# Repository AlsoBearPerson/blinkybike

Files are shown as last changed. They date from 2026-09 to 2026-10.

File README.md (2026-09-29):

# Blinkybike

This is the source for a small hobby bike-modding project,
adding some microcontroller-driven RGB lighting to a bicycle.

If you're curious about how it's built,
here's some of the under-the-hood bits.

As a general principle,
the software is supposed to focus on readability and maintability,
over golfing performance.
However, it is also a prototype, and I'm still learning the language,
so there will be quirks.

## Not a recipe

The project is provided solely for reference, as an example of
some practical application of rust-embedded shenanigans.
In particular, it is NOT intended as a ready-made recipe for
easy adaptation: it may contain assumptions of particular
hardware quirks, undocumented subtlety,
and backwards-incompatible changes may happen at any time as I feel like it.
I'm just one internet-connected potato making things,
I have no bandwidth available for any kind of support efforts.

## Parts

For reference, here's the parts being used to drive this, as-built.
These were what I picked up randomly and should not be read as endorsements,
better parts may exist and I did not do systematic market analysis,
but in the spirit of reproducability, here's the major parts used:

### A bicycle

If you don't know what this is, I can't help you.
Mine's acoustic (not electric, powered entirely by my own two legs).

### Microcontroller

Using a [Pi Pico 2W](https://www.raspberrypi.com/products/raspberry-pi-pico-2/?variant=pico-2-w).

It's more than enough power for what we need,
and BLE support means we can make a control UI driven by a common smartphone,
rather than having to wire up and attach our own switches/buttons/knobs.

### Debug Probe

Not strictly necessary, but very useful for troubleshooting,
I'd highly recommend grabbing a [Pi Debug Probe](https://www.raspberrypi.com/products/debug-probe/),
which can connect to the SWD interface on the pico.
This allows both debugging, and also just reflashing the pico anytime
without having to reboot or fiddle with BOOTSEL buttons.

Then you'll want to grab [probe.rs](https://probe.rs/)
which can upload and run builds, and interface with the `defmt` and `RTT` shenanigans,
so you get cheap accurate logging and even panic stacktraces,
even though you're running on a microcontroller.

### Blinky Bits

I'm using a [LED fake-neon-tube strip](https://www.adafruit.com/product/3869).

Any WS2812-style "neopixel" strip would work,
the nice thing about the fake neon is that it's a pretty omnidirectional glow,
and the diffusion avoids any sharp point lights,
which might be uncomfortable to look at.

BEWARE: This thing takes some specific handling:
it only bends in one axis, which is great for making neon-like signs,
but a problem for us, if we want to fix it to a 3D object.
Internally, it's a flex-PCB LED strip turned sideways,
thus it bends well side-to-side, twists somewhat,
but REALLY dislikes bending up/down,
if you force it you'll likely rip the PCB.
Be generous with bend radiuses, and try to twist before/after bends,
to keep them along the preferred axis.

Note that this one takes 12V power, which is nice to keep amps low,
but means yet more voltages to worry about.

### Level Shifting

This might not be strictly necessary,
but I'm using an [Adafruit Pixel Shifter](https://www.adafruit.com/product/6066).

Note that the strip wants a 12V supply on its power line,
but 5V WS2811-style signals on its data line,
thus we're boosting from the pico's 3.3V logic up to 5V for a good signal.

### Power

I'm using a USB-C powerbank, as it's portable, swappable,
can do many voltages, and may provide basic power diagnostics itself.
I have a spare one I bought on sale which turned out to have a manufacturing
error of some kind, giving it only 1/3rd of advertised capacity.
A fraction of 90Wh is still perfectly fine for driving a little strip for hours,
mine suggests the build is drawing around 3W in typical use.

Nice thing about USB-C is that you can request various voltages,
and powerbanks in particular tend to broadly support many of them,
but check the labeling for what it can do, and test with a multimeter.
You can get various "USB-C PD sink" adapters, for example Adafruit
sells [nice cables](https://www.adafruit.com/product/5450),
we need 12V for the strip.

DON'T send the 12V directly to the microcontroller!
The RT6154 regulator on the pico board is only rated for up to 5.5V in.

The microcontroller gets its power from plain old USB-A off the same
powerbank, with the caveat that it draws so little power that the bank
loves to cut off the port after a few minutes
unless put into "low-power output" mode,
which needs to be re-enabled every 2 hours.
Maybe I'll finangle up a resistive dropper, at some point.

Just in case, make sure to common ground lines together.

This entire setup could work off some AA batteries, or some custom
LiPo setup if you're feeling spicy, powerbank was just the easiest option.

### A smartphone

Using our BLE functionality, we can alter some basic parameters at runtime,
without having to get out a laptop and re-flash the pico.

For now, the protocol we're using is nRF's proprietary "Nordic UART",
which seems to be relatively common as a low-complexity hobby build thing.

To interact with it, I've gotten the best results from the
[nRF Toolbox](https://www.nordicsemi.com/Products/Development-tools/nRF-Toolbox)
app, which comes with a handy little button grid,
so you can pre-program commands to send with one press.
It is probably also compatible with
[Bluefruit Connect](https://play.google.com/store/apps/details?id=com.adafruit.bluefruit.le.connect.v4)
now, which might be easier to get started,
and may have more useful functions for prototyping.

The accepted commands are going to change frequently,
so look for `handle_command` in [the source](https://github.com/AlsoBearPerson/blinkybike/blob/main/src/main.rs#L97)
for a list.

As of now, there's no authentication of any kind,
other than the software only accepting one connected central host at a time.
So there is a risk of random other folks nearby hijacking control,
if they know what to look for, and really want to control brightness/speed.

### Sensing

None of this is being used yet,
but plan is to tie in a BNO085 to have movement feedback into blinkiness.

Also I want to add some sort of basic illumination sensing,
to automatically tamp down brightness in the dark,
for tunnels and nighttime.

## Legality

So, is this actually road legal?
It depends, different jurisdictions will have different opinions.

Different countries, or even different regions within a country,
may well have different ideas.
Some may be more lenient about a little human-powered portable thing
than drivable murder machines,
others will strictly specify permissible lighting of anything with wheels.
And the opinion of the cop in front of you likely overrules anything in the moment.

Anything you build is entirely at your own risk,
and I can make no warranties here.

But we're not here to be a nuisance,
so here's a few general considerations:

* Avoid running things brighter than necessary,
  we're here to be fun blinky, not blind the neighborhood.
* Avoid fast or distracting animations -
  you don't want to hand out migraines,
  blinking in the corner of one's eye is distracting,
  and anyone staring at you isn't looking at the road.
* Avoid potentially ambiguous use of signal colors, for example you might have:
  * white - front of vehicle
  * red - rear of vehicle, braking
  * yellow - hazard, intent-to-turn
  * blue - reserved for emergency vehicles
* Respect the advice of local law enforcement.

When in doubt, this project is meant for artistic purposes only,
for performance and recording on closed areas,
and should be turned off when transiting public roadways.

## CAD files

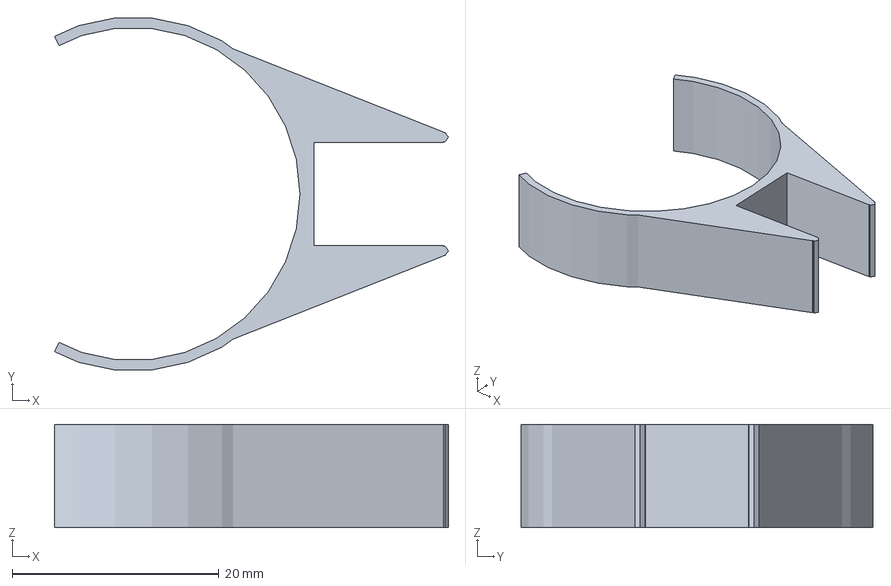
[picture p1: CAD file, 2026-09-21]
extras/strapholder.3mf
38.1 x 34.1 x 10.0 mm

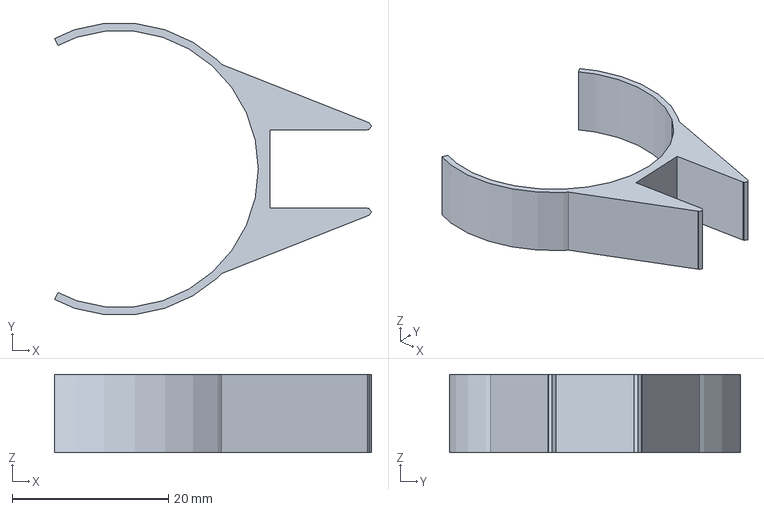
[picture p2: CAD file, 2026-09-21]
extras/strapholder-bottom.3mf
40.6 x 37.3 x 10.0 mm

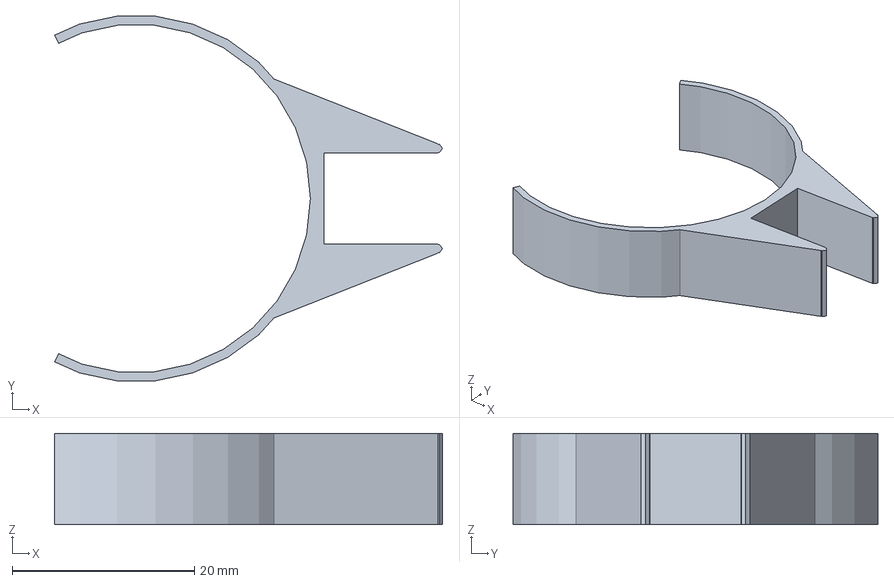
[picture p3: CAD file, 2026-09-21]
extras/strapholder-front.3mf
42.6 x 40.0 x 10.0 mm

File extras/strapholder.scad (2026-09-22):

// A 3D printable for a basic holder to keep the LED strip straight,
// keeping it (mostly) from lying sideways, since that's what it tends
// to do coming out of a sideways twist to go around a bend.
//
// Really just a partial circle the size of the corresponding frame tube,
// with a little triangular gripper on front.
// Not designed to grip with any sort of friction, you'll probably want
// zip ties or such to hold things in place,
// and a few of these holders to keep them from folding.
//
// Frame tube diameter, for my particular bike:
// upper - 32.25mm
// rear - 32.25mm
// bottom - 35.5mm
// front - 38.25mm

diam = 38.25;
// Where the grip polygon goes: A smidge past the main circle,
// for a bit of extra stability.
offset = diam / 2 + 1.5;

// Polygon shape for our "gripper" part:
// a U shaped slot of 10mm wide and 12.5mm deep holds the strip,
// with walls that start 1mm wide and slope outwards at a roughly 2:1 ratio,
// eventually meeting up with the main structure circle.
p = [
  [   0,   5],
  [12.5,   5],
  [12.5,   6],
  [-9.0, 14.5],
  [-9.0,-14.5],
  [12.5,  -6],
  [12.5,  -5],
  [   0,  -5],
  [   0,   5],
];

module clamp() {
    translate([offset, 0])
        polygon(p);
    // To keep the gripper front from being pointy, add small circles.
    // Though considering we're working at 1mm width here,
    // printer filament physics probably would already round these for us.
    translate([offset + 12.5, 5.5])
        circle(d=1);
    translate([offset + 12.5, -5.5])
        circle(d=1);
}

module 2dstuff() {
difference() {
    // Our material: Circular to grab the frame, and the clamp.
    union() {
        // 1mm circle, for now. Will see how that holds up.
        circle(d=diam + 2);
        clamp();
    }
    // Our keep-out: Leave room for the actual frame,
    // then cut out on the opposite side of the clamp,
    // leaving enough circle to weakly grip the frame,
    // without forcing too much of a bend to clamp on.
    union() {
        circle(d=diam);
        polygon([[0, 0], [-30, 60], [-30, -60], [0, 0]]);
    }
}
}

// Extrude all that 10mm wide. Chamfers left as an exercise to the reader.
linear_extrude(10) {
    2dstuff();
}

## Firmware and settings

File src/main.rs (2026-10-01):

#![no_std]
#![no_main]

mod animations;
mod bleuart;
mod utils;

use core::fmt::Write;
use core::sync::atomic::AtomicBool;
use core::sync::atomic::Ordering::Relaxed;

use defmt::{info, unwrap, warn};
use defmt_rtt as _;
use embassy_executor::Spawner;
use embassy_rp::pio::Pio;
use embassy_rp::pio_programs::ws2812::{PioWs2812, PioWs2812Program};
use embassy_rp::{bind_interrupts, dma, peripherals, pio};
use embassy_sync::blocking_mutex::raw::{NoopRawMutex, RawMutex};
use embassy_sync::zerocopy_channel;
use embassy_time::{Duration, Instant, Timer};
use fixed::{traits::Fixed, types::*};
use panic_probe as _;
use smart_leds::RGB8;
use static_cell::StaticCell;

use crate::animations::CanAdvance;
use crate::bleuart::UartMessage;
use crate::flags::*;
use crate::utils::{AtomicFixed, AtomicI8F24, AtomicU8F8};

bind_interrupts!(struct Irqs {
    PIO0_IRQ_0 => pio::InterruptHandler<peripherals::PIO0>;
    PIO1_IRQ_0 => pio::InterruptHandler<peripherals::PIO1>;
    DMA_IRQ_0 => dma::InterruptHandler<peripherals::DMA_CH0>,
        dma::InterruptHandler<peripherals::DMA_CH1>,
        dma::InterruptHandler<peripherals::DMA_CH2>,
        dma::InterruptHandler<peripherals::DMA_CH3>;
});

const N1_LEDS: usize = 20;
const N2_LEDS: usize = 15;
const NUM_LEDS: usize = N1_LEDS + N2_LEDS;
type Pixbuf = [RGB8; NUM_LEDS];

#[embassy_executor::main(
    executor = "embassy_rp::executor::Executor",
    entry = "cortex_m_rt::entry"
)]
async fn main(spawner: Spawner) {
    info!("Start");
    let p = embassy_rp::init(Default::default());

    spawner.spawn(unwrap!(bleuart::run_ble(
        p.PIN_23, p.PIN_25, p.PIO1, p.PIN_24, p.PIN_29, p.DMA_CH2, p.DMA_CH3, spawner,
    )));
    spawner.spawn(unwrap!(process_commands()));

    // We use two tasks, one in charge of calculating pixels,
    // and one in charge of blinking out to the strip.
    // This is probably somewhat excessive, but provides nice separation,
    // and could be split across cores, if needed.
    // We tie them together via a zerocopy channel,
    // which in effect implements double-buffering,
    // while avoiding any unsafe/manual lifetime shenanigans.
    static RAW_BUF: StaticCell<[Pixbuf; 2]> = StaticCell::new();
    static CHANNEL: StaticCell<zerocopy_channel::Channel<'_, NoopRawMutex, Pixbuf>> =
        StaticCell::new();

    let buf = RAW_BUF.init([[RGB8::default(); _]; _]);
    let chan = CHANNEL.init(zerocopy_channel::Channel::new(buf));
    let (send, recv) = chan.split();

    spawner.spawn(unwrap!(producer(send)));
    spawner.spawn(unwrap!(consumer(
        recv, p.PIO0, p.DMA_CH0, p.DMA_CH1, p.PIN_16, p.PIN_17
    )));
}

#[embassy_executor::task]
async fn process_commands() -> ! {
    let r = bleuart::get_receiver();
    loop {
        let v = r.receive().await;
        for cmd in v.split('\n') {
            let mut buf: UartMessage = UartMessage::new();
            let reply = handle_command(cmd, &mut buf).await;
            if reply.is_empty() {
                continue;
            }
            if let Ok(reply) = reply.try_into() {
                bleuart::try_send(reply);
            } else {
                warn!("Reply dropped, too large");
            }
        }
    }
}

const FADE_FACTOR: U8F8 = U8F8::lit("1.5");
const SPEED_FACTOR: I8F24 = I8F24::lit("1.5");

async fn handle_command<'a>(cmd: &str, buf: &'a mut UartMessage) -> &'a str {
    match cmd {
        "B--" => shrink_cmd(&FADE_LEVEL, FADE_FACTOR, "Darker", "Too dark!", buf),
        "B++" => grow_cmd(
            &FADE_LEVEL,
            FADE_FACTOR,
            U8F8::ONE,
            "Brighter",
            "Max bright!",
            buf,
        ),
        "S--" => {
            if clear_paused() {
                return "Unpaused.";
            }
            shrink_cmd(&TIME_MULT, SPEED_FACTOR, "Slower", "Too slow!", buf)
        }
        "S++" => {
            if clear_paused() {
                return "Unpaused.";
            }
            grow_cmd(
                &TIME_MULT,
                SPEED_FACTOR,
                10.into(),
                "Faster",
                "Ludicrous speed!",
                buf,
            )
        }
        "PAUSE" => {
            let val = flip_paused();
            if val { "Unpaused." } else { "Paused." }
        }
        "NEXT" => {
            let val = set_fastforward();
            // Fastforward should clear itself promptly on the next animation frame.
            // If we ever find it already set, something strange might be afoot.
            if val { "Stuck?" } else { "Go next." }
        }
        _ => "???",
    }
}

fn shrink_cmd<'a, F: AtomicFixed>(
    holder: &F,
    factor: F::Value,
    msg: &'a str,
    underflow_msg: &'a str,
    buf: &'a mut UartMessage,
) -> &'a str {
    let cur = holder.get() / factor;
    if cur > 0 {
        holder.set(cur);
        changemsg(msg, cur, buf)
    } else {
        underflow_msg
    }
}

fn grow_cmd<'a, F: AtomicFixed>(
    holder: &F,
    factor: F::Value,
    max: F::Value,
    msg: &'a str,
    overflow_msg: &'a str,
    buf: &'a mut UartMessage,
) -> &'a str {
    let cur = holder.get();
    let mut val = cur.saturating_mul(factor);
    if val == cur && val < F::Value::MAX {
        // Handle edge case of 0x0.01 * 0x1.8 truncating back to 0x0.01
        val += F::Value::DELTA;
    }
    let result = if val < max {
        changemsg(msg, val, buf)
    } else {
        val = max;
        overflow_msg
    };
    holder.set(val);
    result
}

fn changemsg<'a>(
    msg: &'a str,
    val: impl Fixed + defmt::Format,
    buf: &'a mut UartMessage,
) -> &'a str {
    if core::write!(buf, "{}->{:X}", msg, val).is_ok() {
        buf
    } else {
        warn!("Fmt fail/overflow: {:?} / {:?}", msg, val);
        msg
    }
}

#[allow(unused)]
const GAMMA8: [u8; 256] = color_parse::srgb_to_linear_table!();
#[allow(unused)]
const fn gamma(c: RGB8) -> RGB8 {
    RGB8 {
        r: GAMMA8[c.r as usize],
        g: GAMMA8[c.g as usize],
        b: GAMMA8[c.b as usize],
    }
}

mod flags {
    use color_parse::colors_linear;
    use smart_leds::RGB8;
    pub const FLAG_PRIDE: [RGB8; 6] =
        colors_linear![ #E40303, #FF8C00, #FFED00, #008026, #004CFF, #732982];
    pub const FLAG_TRAAANS: [RGB8; 5] =
        colors_linear![ #5BCEFA, #F5A9B8, #FFFFFF, #F5A9B8, #5BCEFA];
    pub const FLAG_LESSBEANS: [RGB8; 7] =
        colors_linear![ #D52D00, #EF7627, #FF9A56, #FFFFFF, #D162A4, #B55690, #A30262];
    pub const FLAG_BI_CYCLE: [RGB8; 5] =
        colors_linear![ #D60270, #D60270, #9B4F96, #0038A8, #0038A8];
    // Welp, good luck displaying "black" on a self-lit medium.
    // Gotta have this one, though.
    pub const FLAG_NUMEROUSBEES: [RGB8; 4] = colors_linear![ #FCF434, #FFFFFF, #9C59D1, #2C2C2C];
    pub const FLAG_PANPANPAN: [RGB8; 3] = colors_linear![ #FF218C, #FFD800, #21B1FF];

    // Long story.
    pub const FLAG_GLETSCHER: [RGB8; 6] =
        colors_linear![ #005CB9, #F38B00, #F4CD00, #FFFFFF, #009BDE, #005CB9 ];

    // A walk through Oklch(0.7, 0.15, x) with small tweaks,
    // see extras/wheelscan.py
    // Makes for arguably a more visually pleasant "color wheel"
    // than just a raw max-RGB wheel,
    // even if it's not as overwhelmingly saturated.
    pub const WHEEL_OKLAB_07: [RGB8; 16] = colors_linear![ #E8729B,
               #ED7472, #E97C48, #DB8912, #C19905, #A1A717,
               #74B34C, #30BA79, #00B8A1, #01B4BF, #05AFDC,
               #43A5F6, #7A98FC, #A28BF3, #C17FDE, #D977C0];
}

// Default brightness at half what we could do,
// still plenty bright for most situations,
// but slightly less ridiculous (though still excessive) at night.
static FADE_LEVEL: AtomicU8F8 = AtomicU8F8::new(U8F8::lit("0.5"));
// Default animation timing is 10s per cycle.
static TIME_MULT: AtomicI8F24 = AtomicI8F24::new(I8F24::lit("0.1"));
// Pausing stops progressing animation time (behaving as if TIME_MULT=0),
// but does not halt redraws altogether.
// This ensures that brightness changes, which kick in on the next redraw,
// still take effect promptly.
static PAUSED: AtomicBool = AtomicBool::new(false);
fn is_paused() -> bool {
    PAUSED.load(Relaxed)
}
// Negates pausedness, returning whether we were paused BEFORE the call.
fn flip_paused() -> bool {
    PAUSED.fetch_not(Relaxed)
}
// Ensures PAUSED=false, returning whether we were paused before.
fn clear_paused() -> bool {
    PAUSED.swap(false, Relaxed)
}
static FAST_FORWARD: AtomicBool = AtomicBool::new(false);
// Ensures FAST_FORWARD=false, returning whether it was true before.
fn clear_fastforward() -> bool {
    FAST_FORWARD.swap(false, Relaxed)
}
// Ensures FAST_FORWARD=true, returning whether it was already true before.
fn set_fastforward() -> bool {
    FAST_FORWARD.swap(true, Relaxed)
}

#[embassy_executor::task]
async fn producer(mut s: zerocopy_channel::Sender<'static, NoopRawMutex, Pixbuf>) {
    const LINEAR: animations::LinRev<N1_LEDS, N2_LEDS> = animations::LinRev;
    let mut a0 = animations::many_flag(
        LINEAR,
        &[
            &FLAG_GLETSCHER,
            &FLAG_BI_CYCLE,
            &FLAG_PRIDE,
            &FLAG_TRAAANS,
            &FLAG_LESSBEANS,
            &FLAG_NUMEROUSBEES,
            &FLAG_PANPANPAN,
        ],
    );
    let a1 = animations::smoothwheel(LINEAR, &WHEEL_OKLAB_07);
    let a2 = animations::rgbwheel(LINEAR);
    loop {
        push(&mut s, &a0, 2).await;
        a0.advance();
        push(&mut s, &a1, 3).await;
        push(&mut s, &a0, 2).await; // Repeat the flag slot, we have many to show.
        a0.advance();
        push(&mut s, &a2, 3).await;
    }
}

// Convert a Duration into fractional fixed-point seconds
fn duration_to_secs(d: Duration) -> I8F24 {
    let mut ticks = d.as_ticks();
    let mut ticks_per_s = Duration::from_secs(1).as_ticks();
    const U32MAX: u64 = u32::MAX as u64;
    // unlikely: If we're dealing with huge values, trim insignificant bits
    while ticks > U32MAX || ticks_per_s > U32MAX {
        ticks >>= 1;
        ticks_per_s >>= 1;
    }
    if ticks_per_s == 0 {
        // Many ticks, left side.
        return I8F24::MAX;
    }
    let ticks = U32F0::from_num(ticks);
    let ticks_per_s = U32F0::from_num(ticks_per_s);
    // While I64F0::wide_div would work, that calls for a 128-bit division,
    // which sounds rather slow on a 32-bit CPU, so let's stick to 32->64 bits.
    let wide_result: U32F32 = ticks.wide_div(ticks_per_s);
    wide_result.saturating_to_num()
}

async fn push<A: animations::Animation>(
    s: &mut zerocopy_channel::Sender<'static, NoopRawMutex, Pixbuf>,
    anim: &A,
    max_iters: usize,
) {
    let mut last_time = Instant::now();
    let mut time_strobe: I8F24 = I8F24::ZERO.into();
    let mut state: A::State = Default::default();
    let mut iter_count = 0;
    loop {
        if clear_fastforward() {
            return;
        }
        let now = Instant::now();
        let since_last = now.saturating_duration_since(last_time);
        last_time = now;

        if !is_paused() {
            let since_last: I8F24 = duration_to_secs(since_last).saturating_mul(TIME_MULT.get());
            time_strobe = time_strobe.saturating_add(since_last);
            if time_strobe > 1 {
                iter_count += 1;
                if iter_count >= max_iters {
                    return;
                }
                time_strobe = I8F24::ZERO;
            }
        }

        run_send(s, |buf| {
            anim.frame(&mut state, time_strobe, buf);
            // Fade each LED by multiplying each color channel with the requested fade.
            // For fades greater than 1, this may saturate some channels at 255,
            // which will likely alter the resulting hue.
            let fade: U8F8 = FADE_LEVEL.get();
            for led in buf {
                *led = led
                    .iter()
                    .map(|c| fade.wide_mul(U8F8::from(c)).saturating_to_num())
                    .collect();
            }
        })
        .await;

        // Pad with a sleep, if needed (and always yields at least once).
        // Differs from Ticker in that there's no accumulated catch-up:
        // Wait is relative to last cycle end, regardless of prior cycles.
        const MIN_LOOP_TIME: Duration = Duration::from_millis(10);
        Timer::at(last_time + MIN_LOOP_TIME).await;
    }
}

#[embassy_executor::task]
async fn consumer(
    mut r: zerocopy_channel::Receiver<'static, NoopRawMutex, Pixbuf>,
    pio: embassy_rp::Peri<'static, embassy_rp::peripherals::PIO0>,
    dma1: embassy_rp::Peri<'static, embassy_rp::peripherals::DMA_CH0>,
    dma2: embassy_rp::Peri<'static, embassy_rp::peripherals::DMA_CH1>,
    pin1: embassy_rp::Peri<'static, embassy_rp::peripherals::PIN_16>,
    pin2: embassy_rp::Peri<'static, embassy_rp::peripherals::PIN_17>,
) {
    let Pio {
        mut common,
        sm0,
        sm1,
        ..
    } = Pio::new(pio, Irqs);
    let program = PioWs2812Program::new(&mut common);
    let mut ws2812_1 = PioWs2812::new(&mut common, sm0, dma1, Irqs, pin1, &program);
    let mut ws2812_2 = PioWs2812::new(&mut common, sm1, dma2, Irqs, pin2, &program);

    loop {
        run_recv(&mut r, async |buf| {
            let f1 = ws2812_1.write_slice(unwrap!(buf.first_chunk::<N1_LEDS>()));
            let f2 = ws2812_2.write_slice(unwrap!(buf.last_chunk::<N2_LEDS>()));
            embassy_futures::join::join(f1, f2).await;
        })
        .await;
        // Compensate for a minor bug in ws2812.write:
        // It waits for DMA to finish, then another 55us for ws2812 latch time.
        // However, the DMA will likely finish as the final word gets loaded
        // into the tx fifo, before the state machine actually sends them out.
        // So we wait another 30us (800kHz * 24 pixels) to catch that last transfer.
        // No need to hold on to the buffer for that wait, though.
        Timer::after(Duration::from_micros(30)).await;
    }
}

// A small ergonomics helper for zerocopy channels:
// Awaits an available send slot, runs the passed closure on it,
// marks the value as ready once it returns.
async fn run_send<M, T, R, F>(s: &mut zerocopy_channel::Sender<'static, M, T>, f: F) -> R
where
    F: FnOnce(&mut T) -> R,
    M: RawMutex,
{
    let mut slot = s.send().await;
    let result = f(&mut *slot); // Explicitly unwrap the smart pointer
    slot.send_done();
    result
}

// As above, but for receiving, and takes an async closure.
// This one can get more finicky with lifetimes,
// but seems to be fine for simple cases.
async fn run_recv<M, T, F, R>(r: &mut zerocopy_channel::Receiver<'static, M, T>, f: F) -> R
where
    F: AsyncFnOnce(&mut T) -> R,
    M: RawMutex,
{
    let mut slot = r.receive().await;
    let result = f(&mut *slot).await;
    slot.receive_done();
    result
}

// Program metadata for `picotool info`.
// This isn't needed, but it's recommended to have these minimal entries.
#[unsafe(link_section = ".bi_entries")]
#[used]
pub static PICOTOOL_ENTRIES: [embassy_rp::binary_info::EntryAddr; 4] = [
    embassy_rp::binary_info::rp_program_name!(c"BlinkyBike"),
    embassy_rp::binary_info::rp_program_description!(
        c"WIP: Using a pi pico 2W to drive a string of ws2812 LEDs."
    ),
    embassy_rp::binary_info::rp_cargo_version!(),
    embassy_rp::binary_info::rp_program_build_attribute!(),
];

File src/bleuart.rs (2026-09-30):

// Rust implementation of nRF's Nordic UART Service (NUS) over BLE,
// on embassy/trouble_host, for a rp235x.
//
// This provides a straightforward way to exchange messages with some central
// host, probably a smartphone. By using NUS, which is already supported by
// various BLE tinkering apps, we skip having to write our own control app,
// though this means we deal in text strings, rather than more structured types.
//
// Maybe in the future we'll rework this to provide a set of native GATT
// controls, so that relevant control knobs can be driven more directly
// by a native client. For now, we don't bother.
//
// The interface to the rest of the system is a pair of embassy_sync Channels,
// buffering messages received from, or to be sent to, a connected central host.
// These seem to act as a packet transport, not a byte stream,
// so newlines are probably optional, messages seem to arrive as sent.
//
// The only other public surface is the `run_ble()` task function,
// which should be spawned soon after HAL initialization.
// It takes ownership of some needed peripherals,
// and will drive hardware and software to provide connectivity,
// so long as the device and the executor spawning this task remain running:
// There are currently no controls exposed to pause or power down BLE again.

use cyw43::{Cyw43439, aligned_bytes, bluetooth::BtDriver};
use cyw43_pio::PioSpi;
use defmt::*;
use embassy_executor::Spawner;
use embassy_futures::select::select;
use embassy_rp::{
    Peri, dma,
    gpio::{Level, Output},
    peripherals::{DMA_CH2, DMA_CH3, PIN_23, PIN_24, PIN_25, PIN_29, PIO1},
    pio::Pio,
};
use embassy_sync::{blocking_mutex::raw::ThreadModeRawMutex, channel::Channel};
use embassy_time::{Duration, Timer};
use static_cell::StaticCell;
use trouble_host::prelude::*;

// Our messages have a fixed maximum size,
// to ensure they can be allocated statically.
// Surely 100 characters should be good enough for anyone. Right?
pub const UART_MSG_SIZE: usize = 100;
pub type UartMessage = heapless::String<UART_MSG_SIZE>;

// Using ThreadModeRawMutex below is somewhat unsafe on the rp235x,
// as it won't handle multi-core access correctly.
// So far, we're only using core 0, so it's fine, for now,
// as long as we keep all access to these channels on the same core/executor.

/// Holds messages from NUS for processing in our application
static RX_CHAN: Channel<ThreadModeRawMutex, UartMessage, 10> = Channel::new();
/// Holds messages from our application to be sent over NUS
static TX_CHAN: Channel<ThreadModeRawMutex, UartMessage, 10> = Channel::new();

// Queue a message to send to a connected host, soon.
// If there is no host connected, we buffer a few messages,
// so a newly connected host may see a replay of what happened while it was away.
// Once the buffer is full, old messages are dropped,
// so the most recent messages eventually get sent.
pub fn try_send(v: UartMessage) {
    if TX_CHAN.is_full() {
        let _ = TX_CHAN.try_receive();
    }
    let _ = TX_CHAN.try_send(v);
}

pub fn get_receiver()
-> embassy_sync::channel::Receiver<'static, ThreadModeRawMutex, UartMessage, 10> {
    RX_CHAN.receiver()
}

// Manually place the large firmware blob into its own link section.
// This allows using "--skip-section .firmware" with probe-rs on reflashing,
// to save time when firmware blobs haven't changed.
// For best results, you'll also want to tweak memory.x to place this section
// at a fixed address, otherwise changes to program size will shift where
// the linker places this object, requiring reflashing anyway.
// A more elaborate trick would be to use rp235x's partition table feature,
// and have picotool upload firmware once. But that's more tools involved,
// and embassy-rp doesn't seem to have great support for navigating existing
// partitions, yet. Also, partitions would round up sizes to 4K multiples,
// unclear if the driver would be cool with that.
//
// Stable rust still doesn't like "const X: [u8; _] = ...",
// so we have to be a bit silly to accurately size the array.
const FW_LEN: usize = include_bytes!("../assets/cyw43-firmware/43439A0.bin").len();
#[unsafe(link_section = ".firmware")]
static FW: cyw43::Aligned<cyw43::A4, [u8; FW_LEN]> =
    // Can't use the aligned_bytes! macro, as that returns a reference to an
    // unsized type, which we couldn't deref and store into a static.
    // We need our static to be exactly the value in place, not merely
    // a reference to some compile-time constant, otherwise our link_section
    // override would merely place the reference, not its pointed-to value.
    cyw43::Aligned(*include_bytes!("../assets/cyw43-firmware/43439A0.bin"));
// We don't bother doing this with the other firmware blobs,
// they're comparatively tiny, at 6K for btfw, vs. the 226K of this chonker.

// Kicks off the entire BLE protocol stack.
// The pins listed here match the connections on a Pi Zero 2W dev board,
// and should not be changed without good reason.
// The PIO and DMA numbers are arbitrary, and could be switched.
// However, as embassy tasks can't be generic, these are just some designated
// peripherals that happened to be otherwise unused at the time.
#[embassy_executor::task]
pub async fn run_ble(
    pwr: Peri<'static, PIN_23>,
    cs: Peri<'static, PIN_25>,
    pio: Peri<'static, PIO1>,
    dio: Peri<'static, PIN_24>,
    clk: Peri<'static, PIN_29>,
    dma1: Peri<'static, DMA_CH2>,
    dma2: Peri<'static, DMA_CH3>,
    spawner: Spawner,
) {
    let fw = &FW;
    let clm = aligned_bytes!("../assets/cyw43-firmware/43439A0_clm.bin");
    let btfw = aligned_bytes!("../assets/cyw43-firmware/43439A0_btfw.bin");
    let nvram = aligned_bytes!("../assets/cyw43-firmware/nvram_rp2040.bin");

    let pwr = Output::new(pwr, Level::Low);
    let cs = Output::new(cs, Level::High);
    let mut pio = Pio::new(pio, crate::Irqs);
    let spi = PioSpi::new(
        &mut pio.common,
        pio.sm0,
        cyw43_pio::RM2_CLOCK_DIVIDER,
        pio.irq0,
        cs,
        dio,
        clk,
        dma::Channel::new(dma1, crate::Irqs),
        dma::Channel::new(dma2, crate::Irqs),
    );

    static STATE: StaticCell<cyw43::State> = StaticCell::new();
    let state = STATE.init(cyw43::State::new());
    let (_net_device, bt_device, mut control, runner) =
        cyw43::new_with_bluetooth(state, pwr, spi, fw, btfw, nvram).await;
    spawner.spawn(unwrap!(cyw43_runner(runner)));
    control.init(clm).await;
    // Our low-level radio hardware is up and running at this point,
    // time to kick off the next layer.
    // We implement our layers via separate embassy tasks for clarity,
    // so stack traces are easier to read.
    // Most of the state lives in StaticCells, or is passed by value.
    spawner.spawn(unwrap!(ble_stack(bt_device, control, spawner)));
}
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

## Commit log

2026-09-17 Initial prototype
2026-09-21 Support dual strips, and a 3D model for basic grip/align gizmos.
    [strapholder-bottom.3mf, strapholder-front.3mf, strapholder.3mf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]
2026-09-22 Finish commenting the print.
    [strapholder.scad]
2026-09-23 BLE UART working (but at what cost?)
2026-09-29 Switch UART message type from heapless:Vec<u8, N> to heapless::String<N>.
    I'm not entirely convinced this is simpler,
    but this does align it better with how we're using it.
2026-10-01 Rejigger command string handling:
    Instead of returning a string by value,
    we now always return a reference,
    but pass in a suitably-lifetimed scratch buffer,
    in case called code needs it.
    This does mean there's an extra copy happening,
    in the scratch-used case,
    as we're turning it into yet another owned string to hand off to the channel.
    This could be avoided, with sufficient trickery,
    but that gets a tad hairy,
    and we're unlikely to notice,
    given commands are likely flowing at <1/s rates.
    [main.rs]
